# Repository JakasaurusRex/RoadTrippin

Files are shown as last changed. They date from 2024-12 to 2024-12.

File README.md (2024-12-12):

# Road Trippin' 🚗🏞🏝
Interactive Road Trip poster you can hang on your wall! Add pins for places you have been to and watch the states you have visited light up! Check out my [blog posts](https://jakasaurusrex.github.io/CakeBlog/) to learn more about it! 

***

## Repo Organization

There are only two files in the project. The file RoadTrippin.ino is the code that allows you to enable the lights connected to the poster when touching the ESP32's touch capacitive sensors! 

The other file, RoadTrippin.dxf, contains the laser cutting sketch I used to cut my map!

## The final product!!

https://github.com/user-attachments/assets/daa2bce8-5e1f-463f-a1db-0b114a8d54d9

https://github.com/user-attachments/assets/3a676e5f-96ef-4e44-b18f-90c4ee2a2c48

https://github.com/user-attachments/assets/1af5664a-9a55-464c-b7fb-2d921442d5cf

https://github.com/user-attachments/assets/1d52dfcd-264f-49d4-b72b-c0ab49cd1998

## What is this? 🎨

This is an interactive poster made for the final project for Creative Embedded systems. We were tasked to use our knowledge and skills acquired by working with the ESP32 over the semester to design a project that has interactive features and sits in an enclosure. My goal was to create a interactive poster inspired by Crafted Stories by Irene Posch, a project that I investigated earlier in the semester for our related works project! The interactive poster would allow you to place pins on a map to chart out a roadtrip on a map of the east coast states. Placing pins in holes in states would light up the state indicating you had been there. All the technical components would be contained in the back of the poster and the ESP32 is contain at the bottom allowing for you to plug in the poster.

Here are some of the tools and materials that I used to create the project and what you would need to replicate it:  
- ESP32 TTGO T-display + USB-C Cable
- Plywood + Laser Cutter
- Adobe Illustrator for creating the sketch for cutting and scanning
- Soldering Iron and many wires for soldering
- Arudino IDEs
- Conductive Tape

## How to Build 🔨
1. Clone the repo!
```bash
git clone https://github.com/JakasaurusRex/RoadTrippin.git
```
2.  Download RoadTrippin.dxf or create your own sketch for cutting out the map!
3.  Laser cut and assemble the map! I used hot glue and tape to keep things in tact! Additionally, I cut out the states and then shrunk them and connected them together and cut again to create the multi-layered effect seen in my project!
4.  Design and setup your circuit for however many states you want to be able to light up. My ESP32 only had 7 touch capacitive sensors and 7 additional pins, so I could only light 7 states. 
5.  Hook up the circuitry to the map and setup the capacitive touch capabilties!
6.  Change the pins on the arduino program to correspond with your respective pins
7.  Set up the poster for display and plug it in!

## How I made it! ⚙️✏️

This section will be divided into multiple unordered parts that all came together in the end:
- Designing the Map
- Desgining the Circuit
- Setting up the capacitive touch capabilities.

## Designing the Map!
Screenshot 2024-12-12 at 1 07 19 AM
Screenshot 2024-12-12 at 1 07 13 AM

My original goal for the map was inspired by a poster like this one I found online:
Screenshot 2024-12-12 at 1 09 32 AM

With this in mind, I started designing my map on illustrator. I originally had planned to make an entire US map, but I limited the scope of the project down to just the East Coast states. After image tracing a map and seperating out all the states and clearing it up I ended up making my sketch to be passed to the laser cutter!

Screenshot 2024-12-12 at 1 11 42 AM

With my laser cut sketch ready, I brought it to my laser cutter and I cut out the states and the outline. After doing this, I unioned the area of all of the states and shrunk that down and cut that out of a rectangle of wood. Then I glued together my states and attached them to pegs and glued that structure to the cutout rectangle. This created the 3D effect seen when viewing the poster. I additionally added some text in the laser cutter software that says "Beautiful Appalachia" to commemerate my beautiful east coast road trip! 

The results are shown below! It turned out super cool and theres lots of space in the back of the design for the circuitry to be placed! 

Screenshot 2024-12-12 at 1 06 45 AM

## Designing the Circuit
Screenshot 2024-12-12 at 1 05 58 AM
Screenshot 2024-12-12 at 1 17 24 AM

Above are the diagrams I created before setting up my circuit! I had planned to setup a bunch of circuits with LEDs to light up the states. I would set the LED pins to high when a user had pressed a touch capacitive sensor of the respective state. I planned to use conductive tape to keep the circuit low profile when connecting everything to the map in the end. Here are some photos I took while assembling the circuit!

Screenshot 2024-12-12 at 1 27 02 AM
Screenshot 2024-12-12 at 1 27 18 AM

In the end. I ended up using the conductive tape for the ground strip mostly and making connections stronger. I ended up using alligator clips to clip the LED circuits to ground, as that was just easiest to get setup while I was approaching the deadline for the project. It also gave me the flexibility to move stuff around more easily, but it did take up more space in the enclosure which was frustrating. 

The rest of the circuitry is soldered together! I labeled almost every cable so that it was clear what cable did what and to avoid confusion in the future. This was super useful when setting up the capacitive touch capabilties! The only issue that arose was that 2 of the pins on my board were not working, so in the end I only had 5 LEDs that would light up. 

## Setting up the capacitive touch capabilities

The last thing that I did when assembling this project was set up the capacitive touch capabailities. In order to acheive this, I used the capacitive touch sensors on the ESP32 board. There are 7 touch capacitive sensors on the board that change values when a conductive material touches them. To active them, I planned on soldering wires to the pins and then connecting the wires to aluminum foil or copper tape. Then I could touch the sensing area beneat the map with a pin with copper tape around it. 

For the most part, I was working on this concurrently with the circuit designing. Here is a gif showcasing my first bit of progress where I got a capacitive touch sensor to turn on one of the LEDs. 



After doing this, I was able to extend this to work with multiple LEDs! 

https://github.com/user-attachments/assets/051fd605-8ccc-4d97-9e67-a0f030736416

In the video, the values that I checked as a threshhold were a little too high! I lowered them later from a threshold pin value from 60 to 50. This stopped the flickering seen in the video. 

I realized when setting up the map that the circuits would not be able to be complete withour a source of electricity, like our bodys. So instead of always keeping the light on, I changed the code to keep track of when the the circuit was completed and to change the value of the light when the circuit is complete. For example, when you complete the circuit for the first time with a conductive pin, the light will turn on. Then when you pick up the pin again to remove it, you complete the circuit again and the light turns back off. 

I used this to create an example with one of the states in the demo video shown below. 

https://github.com/user-attachments/assets/c8f70d38-c7c4-49fb-8d54-8e2cc2e142f2

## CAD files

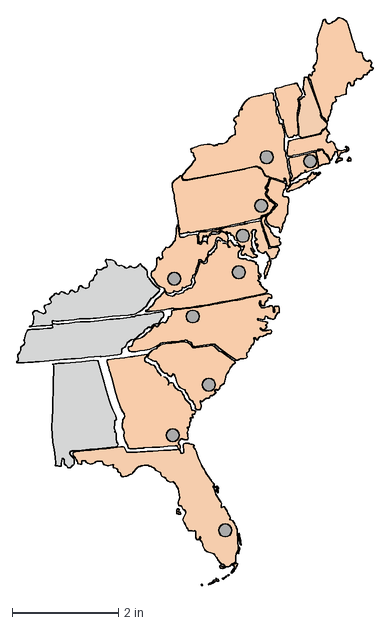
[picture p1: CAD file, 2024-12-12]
RoadTrippin.dxf
6.73 x 10.7 in

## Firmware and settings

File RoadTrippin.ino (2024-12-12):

// ESP32 Touch Test
// Just test touch pin - Touch0 is T0 which is on GPIO 4.

#define SENSITIVITY 50

#define State1LED 25
#define State1Touch 27
int State1On = 0;
int State1Changed = 0;

#define State2LED 26
#define State2Touch 33
int State2On = 0;
int State2Changed = 0;

#define State3LED 22
#define State3Touch 32
int State3On = 0;
int State3Changed = 0;

#define State4LED 21
#define State4Touch 12
int State4On = 0;
int State4Changed = 0;

#define State5LED 17
#define State5Touch 13
int State5On = 0;
int State5Changed = 0;

void setup() {
  Serial.begin(115200);
  pinMode(State1LED, OUTPUT);
  pinMode(State2LED, OUTPUT);
  pinMode(State3LED, OUTPUT);
  pinMode(State4LED, OUTPUT);
  pinMode(State5LED, OUTPUT);
}

void loop() {
  /* State 1 */
  // Check for changes in touch value - if enough time has passed switch LED
  if (touchRead(State1Touch) < SENSITIVITY) {
    if(State1Changed + 500 < millis()) {
      State1On = State1On ? 0 : 1;
      State1Changed = millis();
    }
  }

  // set LED value based on previous 
  if(State1On) {
    digitalWrite(State1LED, HIGH);
  } else {
    digitalWrite(State1LED, LOW);
  }

  /* State 2 */
  if (touchRead(State2Touch) < SENSITIVITY) {
    if(State2Changed + 500 < millis()) {
      State2On = State2On ? 0 : 1;
      State2Changed = millis();
    }
  }

  if(State2On) {
    digitalWrite(State2LED, HIGH);
  } else {
    digitalWrite(State2LED, LOW);
  }

  /* State 3 */
  // Check for changes in touch value - if enough time has passed switch LED
  if (touchRead(State3Touch) < SENSITIVITY) {
    if(State3Changed + 500 < millis()) {
      State3On = State3On ? 0 : 1;
      State3Changed = millis();
    }
  }

  // set LED value based on previous 
  if(State3On) {
    digitalWrite(State3LED, HIGH);
  } else {
    digitalWrite(State3LED, LOW);
  }

  /* State 4 */
  // Check for changes in touch value - if enough time has passed switch LED
  if (touchRead(State4Touch) < SENSITIVITY) {
    if(State4Changed + 500 < millis()) {
      State4On = State4On ? 0 : 1;
      State4Changed = millis();
    }
  }

  // set LED value based on previous 
  if(State4On) {
    digitalWrite(State4LED, HIGH);
  } else {
    digitalWrite(State4LED, LOW);
  }

  /* State 5 */
  // Check for changes in touch value - if enough time has passed switch LED
  if (touchRead(State5Touch) < SENSITIVITY) {
    if(State5Changed + 500 < millis()) {
      State5On = State5On ? 0 : 1;
      State5Changed = millis();
    }
  }

  // set LED value based on previous 
  if(State5On) {
    digitalWrite(State5LED, HIGH);
  } else {
    digitalWrite(State5LED, LOW);
  }
}
